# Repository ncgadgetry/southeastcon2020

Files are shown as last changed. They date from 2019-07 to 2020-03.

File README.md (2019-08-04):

# Southeastcon 2020 

This github contains the rules, arena control software and hardware, and other related files for the IEEE Southeastcon 2020 hardware competition to be held in Raleigh, NC on March 14, 2020.

# Contents:

* Rules:

   Latest copy of the rules, and historical copies of earlier versions.

* ArenaControl:

   Release of the Arduino code and hardware for the arena electronics.
   Please read the comments in the main ArenaControl.h file for an offer
   of fame (and 'fortune') for helping locate and resolve issues in the code.

* 3D_Files:

   Contains the OpenSCAD source code for generating the 3D images of the 
   arena in the rules, as well as the generated photos.

You can find out more about SoutheastCon 2020, including the other
competitions (software, hackathan, website, T-shirt design, ethics)
at the official SoutheastCon page here:

   https://attend.ieee.org/southeastcon-2020/

Have fun, and I hope to see you in Raleigh in March, 2020!

---------

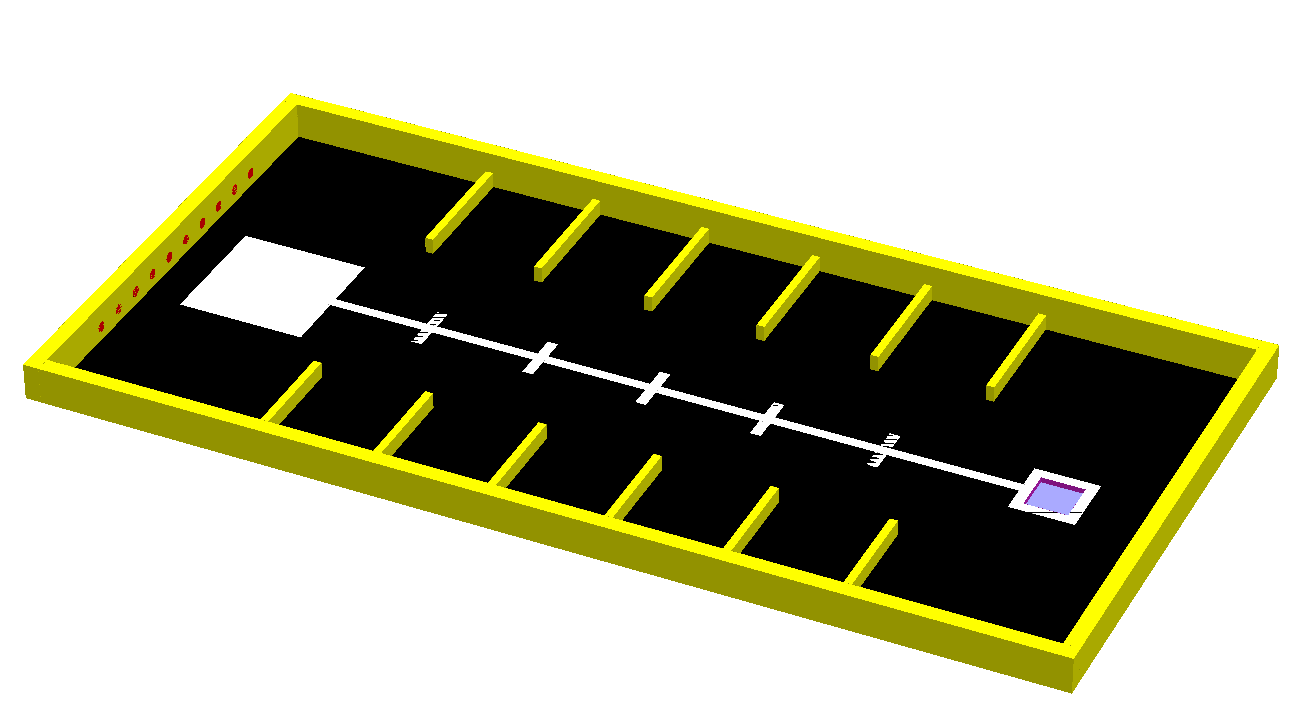
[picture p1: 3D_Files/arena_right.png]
Arena view


---------

Fun table #1 - how high a stack of Lego bricks can you build if you have N
of each color? For example, if you have one of each color, you can go 3.14,
but then run out when you hit 3.141. This table gives you that detail
for up to 25x of each color:

| #bricks | max seq | height |
|:---:|:-----:|:-----:|
| 1 | 3 | 2.3" |
| 2 | 10 | 7.6" |
| 3 | 17 | 12.9" |
| 4 | 24 | 18.1" |
| 5 | 25 | 18.9" |
| 6 | 27 | 20.4" |
| 7 | 43 | 32.5" |
| 8 | 46 | 34.8" |
| 9 | 58 | 43.8" |
| 10 | 62 | 46.9" |
| 11 | 79 | 59.7" |
| 12 | 80 | 60.5" |
| 13 | 100 | 75.6" |
| 14 | 107 | 80.9" |
| 15 | 113 | 85.4" |
| 16 | 124 | 93.7" |
| 17 | 134 | 101.3" |
| 18 | 147 | 111.1" |
| 19 | 150 | 113.4" |
| 20 | 152 | 114.9" |
| 21 | 161 | 121.7" |
| 22 | 171 | 129.3" |
| 23 | 186 | 140.6" |
| 24 | 197 | 148.9" |
| 25 | 204 | 154.2" |

---------

Fun table #2 - if you want to build a stack of a specific height, how many
blocks of each color do you need? Which color runs out the fastest at
any specific height, etc?

| count | BLACK | BROWN | RED | ORANGE |YELLOW | GREEN | BLUE | VIOLET | GRAY |WHITE |
|:---:|:---:|:---:|:---:|:---:|:---:|:---:|:---:|:---:|:---:|:---:|
| 1 | 0 | 0 | 0 | 1 | 0 | 0 | 0 | 0 | 0 | 0 |
| 2 | 0 | 1 | 0 | 1 | 0 | 0 | 0 | 0 | 0 | 0 |
| 3 | 0 | 1 | 0 | 1 | 1 | 0 | 0 | 0 | 0 | 0 |
| 4 | 0 | 2 | 0 | 1 | 1 | 0 | 0 | 0 | 0 | 0 |
| 5 | 0 | 2 | 0 | 1 | 1 | 1 | 0 | 0 | 0 | 0 |
| 6 | 0 | 2 | 0 | 1 | 1 | 1 | 0 | 0 | 0 | 1 |
| 7 | 0 | 2 | 1 | 1 | 1 | 1 | 0 | 0 | 0 | 1 |
| 8 | 0 | 2 | 1 | 1 | 1 | 1 | 1 | 0 | 0 | 1 |
| 9 | 0 | 2 | 1 | 1 | 1 | 2 | 1 | 0 | 0 | 1 |
| 10 | 0 | 2 | 1 | 2 | 1 | 2 | 1 | 0 | 0 | 1 |
| 11 | 0 | 2 | 1 | 2 | 1 | 3 | 1 | 0 | 0 | 1 |
| 12 | 0 | 2 | 1 | 2 | 1 | 3 | 1 | 0 | 1 | 1 |
| 13 | 0 | 2 | 1 | 2 | 1 | 3 | 1 | 0 | 1 | 2 |
| 14 | 0 | 2 | 1 | 2 | 1 | 3 | 1 | 1 | 1 | 2 |
| 15 | 0 | 2 | 1 | 2 | 1 | 3 | 1 | 1 | 1 | 3 |
| 16 | 0 | 2 | 1 | 3 | 1 | 3 | 1 | 1 | 1 | 3 |
| 17 | 0 | 2 | 2 | 3 | 1 | 3 | 1 | 1 | 1 | 3 |
| 18 | 0 | 2 | 2 | 4 | 1 | 3 | 1 | 1 | 1 | 3 |
| 19 | 0 | 2 | 2 | 4 | 1 | 3 | 1 | 1 | 2 | 3 |
| 20 | 0 | 2 | 2 | 4 | 2 | 3 | 1 | 1 | 2 | 3 |
| 21 | 0 | 2 | 2 | 4 | 2 | 3 | 2 | 1 | 2 | 3 |
| 22 | 0 | 2 | 3 | 4 | 2 | 3 | 2 | 1 | 2 | 3 |
| 23 | 0 | 2 | 3 | 4 | 2 | 3 | 3 | 1 | 2 | 3 |
| 24 | 0 | 2 | 3 | 4 | 3 | 3 | 3 | 1 | 2 | 3 |
| 25 | 0 | 2 | 3 | 5 | 3 | 3 | 3 | 1 | 2 | 3 |
| 26 | 0 | 2 | 3 | 6 | 3 | 3 | 3 | 1 | 2 | 3 |
| 27 | 0 | 2 | 3 | 6 | 3 | 3 | 3 | 1 | 3 | 3 |
| 28 | 0 | 2 | 3 | 7 | 3 | 3 | 3 | 1 | 3 | 3 |
| 29 | 0 | 2 | 4 | 7 | 3 | 3 | 3 | 1 | 3 | 3 |
| 30 | 0 | 2 | 4 | 7 | 3 | 3 | 3 | 2 | 3 | 3 |
| 31 | 0 | 2 | 4 | 7 | 3 | 3 | 3 | 2 | 3 | 4 |
| 32 | 0 | 2 | 4 | 7 | 3 | 4 | 3 | 2 | 3 | 4 |
| 33 | 1 | 2 | 4 | 7 | 3 | 4 | 3 | 2 | 3 | 4 |
| 34 | 1 | 2 | 5 | 7 | 3 | 4 | 3 | 2 | 3 | 4 |
| 35 | 1 | 2 | 5 | 7 | 3 | 4 | 3 | 2 | 4 | 4 |
| 36 | 1 | 2 | 5 | 7 | 3 | 4 | 3 | 2 | 5 | 4 |
| 37 | 1 | 2 | 5 | 7 | 4 | 4 | 3 | 2 | 5 | 4 |
| 38 | 1 | 3 | 5 | 7 | 4 | 4 | 3 | 2 | 5 | 4 |
| 39 | 1 | 3 | 5 | 7 | 4 | 4 | 3 | 2 | 5 | 5 |
| 40 | 1 | 3 | 5 | 7 | 4 | 4 | 3 | 3 | 5 | 5 |
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

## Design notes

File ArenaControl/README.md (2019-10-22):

# Southeastcon 2020 Arena control code

This is the Arduino control code for the arena. It is designed to run
on an Arduino Mega (1280 or 2560).

The 10 push buttons and 10 LEDs are wired to pins 26 - 35 as shown below:

     ------  -- -- -- -- -- -- -- -- -- --
     ID #     0  1  2  3  4  5  6  7  8  9
     ------  -- -- -- -- -- -- -- -- -- --
     LED     26 28 30 32 34 36 38 40 42 44 
     BUTTON  27 29 31 33 35 37 39 41 43 45
     ------  -- -- -- -- -- -- -- -- -- --

The LEDs are wired such that the cathodes of all the LEDs are tied to
ground and the anodes tied to the pins listed above.

The button switches are wired such that one half of each button is
connected to ground and the other side to the pin listed above.

Note it is possible to run a single ground wire across all 10x buttons
tying the 20x points of the LEDs and switches together. To make it 
easier, I used a 22 gauge uninsulated wire and just stiched it through
all the pins (orienting the buttons so that the LED cathode and one
side of the switch is nearest the floor.

That leaves one ground connection for all 10x switches, followed by
20x additional wires as shown in the table above.

I used the following Arduino screw shield for making the connections 
to the Arduino and the buttons and LEDs:

https://www.amazon.com/gp/product/B01N2N7LZA/ref=ppx_yo_dt_b_asin_title_o09_s00?ie=UTF8&psc=1

This should be clear enough without a schematic, but if there is any
question, please let me know.

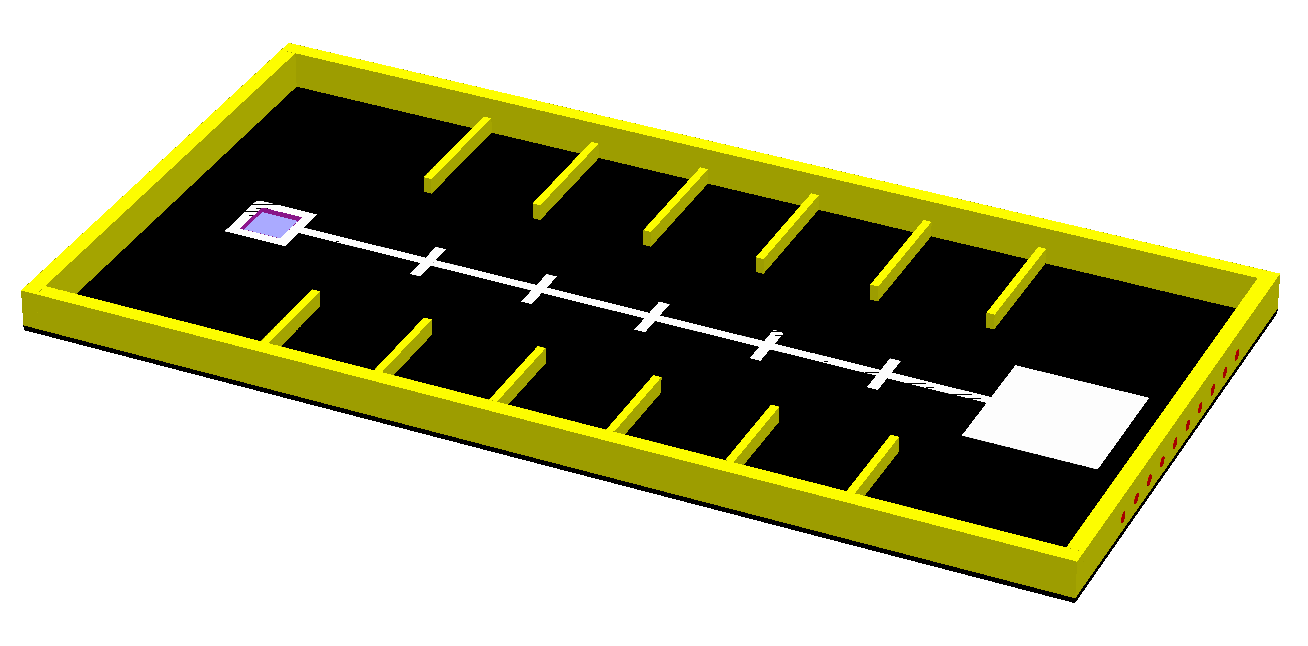
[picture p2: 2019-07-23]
3D_Files/arena_left.png

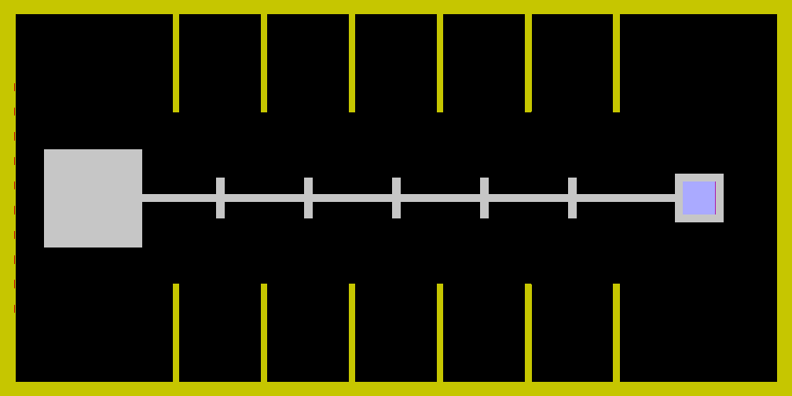
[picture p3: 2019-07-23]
3D_Files/arena_top.png

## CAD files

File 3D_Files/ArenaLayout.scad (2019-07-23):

// ****************************************************************
// 2020 IEEE SoutheastCon Hardware Competition
// Pi-Day competition
// ****************************************************************

// Conversion factors
inch  = 25.4; // mm to inch conversion
fudge = 0.1;  // mm for z-fighting

// Standard lumber dimensions
by1 = 0.75*inch;
by2 = 1.5*inch;
by4 = 3.5*inch;
halfInchPly = 15/32*inch; // nominal 0.5"

// Arena drawFloor dimensions
arenaX = 8*12*inch;
arenaY = 4*12*inch;
arenaZ = halfInchPly;

// Arena colors
floor_color  = "black";
wall_color   = "yellow";
stripe_color = "white";
button_color = "red";

stripeWidth = 1*inch;
markerWidth = 5*inch;

// Starting square and tower hole dimensions
startSquare = 12*inch;
startCenterOffset = by2 + 9.5*inch;
holeSize    = 4*inch;
holeCenterOffset = arenaX - by2 - 9.5*inch;

binWidth = 10*inch;
binDepth = 12*inch;
bin1Xoffset = arenaX/2 - (2.5*binWidth) - 3*by1;

buttonSpacing = 3*inch;



// ****************************************************************
// Draw the center line and the bin navigation marker lines
// ****************************************************************

module drawFloorLines()
{
    color(stripe_color) {

        // Stripe down the middle of the bins
        translate([startCenterOffset, (arenaY-stripeWidth)/2, arenaZ])
           cube([holeCenterOffset - startCenterOffset, stripeWidth, fudge]);

        // Draw the alignment markers for each bin on middle line
        for(bin=[0:4]) {
           translate([bin1Xoffset + 
                     (bin+1)*by1 + 
                     (bin+0.5)*binWidth -
                     stripeWidth/2,
                     (arenaY-markerWidth)/2, arenaZ])
              cube([stripeWidth, markerWidth, fudge]);
        }

        // Draw the square around the tower hole
        translate([holeCenterOffset,arenaY/2,arenaZ])
           cube([holeSize+2*stripeWidth,
                 holeSize+2*stripeWidth,
                 fudge], center=true);

    }
}


// ****************************************************************
// Draw the starting square
// ****************************************************************

module drawStartingSquare()
{
    color(stripe_color) 
        translate([startCenterOffset, arenaY/2, arenaZ])
        cube([startSquare, startSquare, fudge], center=true);
}


// ****************************************************************
// Draw the floor of the arena (4' x 8' black plywood), with a hole
//    cut out of it on end for the stacking tower (teams are 
//    responsible for providing their own stacking surface to 
//    place within the hold to isolate it from the vibrations of
//    the arena floor)
// ****************************************************************

module drawFloor()
{
    difference() {
       union() {
           // First draw the plywood floor
           color(floor_color) 
               cube([arenaX, arenaY, arenaZ]);
           drawFloorLines();
           drawStartingSquare();
       }

       // Then cut a hole out of the middle of it
       translate([holeCenterOffset,arenaY/2,-fudge])
          cube([holeSize,holeSize,(arenaZ+fudge)*3], center=true);
    }
}


// ****************************************************************
// Draw the 2x4 walls
// ****************************************************************

module drawWalls()
{
    color(wall_color) union() {

        // left wall
        translate([by2, 0, arenaZ]) 
           cube([arenaX-by2, by2, by4]);

        // right wall
        translate([0, arenaY-by2, arenaZ]) 
           cube([arenaX-by2, by2, by4]);

        // front wall (nearest tower hole)
        translate([arenaX-by2, by2, arenaZ]) 
           cube([by2, arenaY-by2, by4]);

        // back wall (pushbutton wall)
        translate([0, 0, arenaZ]) 
           cube([by2, arenaY-by2, by4]);
    }
}


// ****************************************************************
// Each bin wall is a 1x2, mounted with the 3/4" side on the plywood
//    and the 1.5" standing vertical - one wall between each bin and
//    since we have 5 bins on each wall, that is 6 walls on each side
// ****************************************************************

module drawBinWalls()
{
    color(wall_color) {

        for(wall=[0:5]) {
           translate([bin1Xoffset + wall*(binWidth+by1), 0, arenaZ]) {
              translate([0, by2, 0])
                 cube([by1,binDepth,by2]);
              translate([0, arenaY - by2 - binDepth, 0])
                 cube([by1,binDepth,by2]);
           }
        }
    }
}



// ****************************************************************
// Draw the pushbuttons
// ****************************************************************

module drawPushbuttons()
{
    for(button=[0:9]) {
        translate([by2, 
                   (button - 4.5) * buttonSpacing + arenaY/2,
                   by4/2])
        rotate([0, -90, 0])
            color(button_color)
               cylinder(r=0.5*inch, h=by2+fudge);
    }
}


// ****************************************************************
// Draw the entire arena by invoking each of the arena drawing modules
// ****************************************************************

module drawArena()
{
    drawFloor();
    drawWalls(); 
    drawBinWalls();
    drawPushbuttons();
}


// ****************************************************************
// Draw the arena, centering it over [0,0,0]
// ****************************************************************

translate([-arenaX/2,-arenaY/2, 0]) 
   drawArena();    

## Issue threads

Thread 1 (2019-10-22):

Arduino Code Not Counting First Incorrectly Pressed Button

ammrat13, 2019-10-22:
I was put in charge of simulating the button pushing code for Georgia Tech's IEEE Robotics Team, and while doing so, I think I uncovered a bug. I essentially did my best to copy your `ArduinoControl.ino` file as closely as possible. I noticed that, when testing to make sure incorrect presses are scored correctly (which I did by pressing `0` a thousand times), I recieved a score one lower than expected. I recieved a score of `999` instead of `1000`.

I traced through both my and your code and found the relevant source lines in my code to be `simulator/Buttons.py` lines `271` to `285`, which correspond to `ArduinoControl.ino` lines `257` to `298`. It seems that on the first incorrect press (`inSequence == true` and `newPress == true` and `buttonState[digit].buttonState == false`), your code correctly sets `numSequenced` to `piDigitPosn` but forgets to increment `extraNotPressed`.

The code is available on our repository: [GT-IEEE-Robotics/Simulator2020](https://github.com/GT-IEEE-Robotics/Simulator2020) commit `7a4a020` if you'd like to check this.

ncgadgetry, 2019-10-22:
Thank you for a valid bug report and code analysis. I will update the code to reflect your bug report in a few days and give you credit for the bug.

Thanx!

ncgadgetry, 2019-10-22:
Issue resolved in latest push - thanx!

I also added your name to the list of contributors for the code!

Closed 2019-10-22.

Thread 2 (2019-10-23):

Arduino Mega 2560 running out of dynamic memory when using ArenaControl code

mdixson2, 2019-10-23:
I have downloaded the git repo as a zip file. I opened the ArenaControl code using the Arduino 1.8.10 IDE. When uploading it to a Mega 2560 Arduino, an error occurs. It states:

"Arduino: 1.8.10 (Windows 10), Board: "Arduino/Genuino Mega or Mega 2560, ATmega2560 (Mega    2560)
Sketch uses 13930 bytes (5%) of program storage space. Maximum is 253952 bytes.
Global variables use 10284 bytes (125%) of dynamic memory, leaving -2092 bytes for local variables. Maximum is 8192 bytes.
Not enough memory;
Error compiling for board Arduino/Genuino Mega or Mega 2560."

Is there a fix for this issue?

mdixson2, 2019-10-23:
Thank you. That works

mlaga97, 2019-10-23:
You'll likely want to keep the issue open until the issue has been resolved on the master branch.

Closed 2019-10-23.

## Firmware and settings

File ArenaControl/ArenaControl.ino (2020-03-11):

/**
 * SoutheastCon 2020 Arena control - ArenaControl.cpp
 *
 * Pin assignments, as well as a challenge to the code reviwers
 *    to find bugs, and the list of those who helped, are listed
 *    in the ArenaControl.h file
 *
 */
 
#include "Arduino.h"
#include "ArenaControl.h"
#include "pi10000.h"


/**
 * buttonPressed - returns true if switch is depressed, else false 
 *   
 * The switch input is active-low, as the other side of the switch
 *    is tied to ground. This allows connecting all 10x of the 
 *    switches to all 10x of the LED returns together with one
 *    ground wire (see photos in hw-uploads channel)
 */
boolean buttonPressed(int id) {
   return !digitalRead(BUTTON_PIN(id));   
}


/**
 * setLED - turns on the LED if is_on is true, else turns it off
 */
void setLED(int id, boolean is_on) {
   digitalWrite(LED_PIN(id), (is_on ? HIGH : LOW));
}


/**
 * setAllLEDs - sets all the LEDs to either on or off
 */
void setAllLEDs(boolean is_on) {

   int led_id;
   
   for (led_id=0; led_id < NUM_BUTTONS; led_id++) {
      setLED(led_id, is_on);
   }
}


/**
 * piDigit - returns the 0..9 value of the dig at posn
 */
int piDigit(int posn) {
   return pgm_read_byte_near(pi + posn) - '0';
}


/**
 * flashAllLEDs - turns all the LEDs on, and sets a timeout of when to
 *    turn them all off. If called again before the timeout is up, it 
 *    just resets the timeout (so a fast robot continuing to press the
 *    wrong button will not see the LEDs go off, but will continue to 
 *    count as invalid digits if the delay is more than the timeout)
 */
void flashAllLEDs() {

   // Turn on all the LEDs, and set a time to turn them off again
   setAllLEDs(true);
   flashTimeout = millis() + FLASH_INTERVAL;
}


/**
 * Scan all the buttons, debouncing each, and sets newPress true if at 
 *   least one of the buttons transitioned from not pressed to pressed
 *   on this pass, and returns the count of on buttons in numPressed
 * 
 * The debounce logic is based on the example here of one button:
 *    http://www.arduino.cc/en/Tutorial/Debounce
 */
void debounceButtons(boolean *newPress, int *numPressed) {

   int  digit;
   uint32_t now_us = micros();
   
   *newPress = false;
   *numPressed = 0;
   
   // Scan each of the buttons   
   for (digit=0; digit < NUM_BUTTONS; digit++) {
      
     // Read the state of the switch into a local variable:
     int reading = buttonPressed(digit);
   
     // Check to see if you just pressed the button
     // (i.e. the input went from false to true), and you've waited long enough
     // since the last press to ignore any noise:   
     
     // If the switch changed, due to noise or pressing:
     if (reading != buttonState[digit].lastButtonState) {
        
       // Reset the debouncing timer
       buttonState[digit].lastDebounceTime = now_us;
     }
   
     // whatever the reading is at, it's been there for longer than the debounce
     // delay, so take it as the actual current state:
     if ((now_us - buttonState[digit].lastDebounceTime) >= DEBOUNCE_DELAY) {
  
       // if the button state has changed:
       if (reading != buttonState[digit].buttonState) {
         buttonState[digit].buttonState = reading;

         // If any button was just pressed, we set the new press boolean
         if (buttonState[digit].buttonState) {
            *newPress = true;
         }
       }
     }

   // If this button is on, increment our count of numPressed       
   if (buttonState[digit].buttonState) {
      (*numPressed)++;
   }
   
   // save the reading. Next time through the loop, it'll be the lastButtonState:
   buttonState[digit].lastButtonState = reading;
   }
}


/**
 * Calculate and return the current score
 */
long currentScore() {

   // 10 points for each one sequenced correctly, plus 1 point
   //   (max of 100) for those not sequenced correctly
   return (numSequenced * 10L) + min(extraNotSequenced, 100);
}


/**
 * Check to see if the optional controller is attached, and if so, use it to start and
 *     stop the match, and to display the status and score
 * The optional controller is the same one used in the 2017 SoutheastCon page and
 *     consists of a 4x20 LCD, I2C to LCD controller, and push buttons on A0 for
 *     start and A3 for stop
 */
bool controllerInstalled() {

   // Setup the button start/stop pins on the Arduino
   pinMode(BUTTON_START, INPUT_PULLUP);
   pinMode(BUTTON_STOP,  INPUT_PULLUP);

   // Check if the optional controller LCD is attached
   Wire.begin();
   Wire.beginTransmission(LCD_ADDRESS);
   bool installed = (0 == Wire.endTransmission());

   // If not, then display a status to the Arduino monitor
   if (false == installed) {
      Serial.println(F("Optional LCD controller not found"));
      Serial.println(F("Start the competition by briefly pressing any button\n"));

   // Else clear the LCD display and display start instructions
   } else {
      lcd.init();
      lcd.backlight();
      lcd.home();

      lcd.print("SoutheastCon 2020");

      lcd.setCursor(0, 1);
      lcd.print("Do you want to...");
      lcd.setCursor(0, 2);
      lcd.print("    ...play a game?");

      lcd.setCursor(0,3);
      lcd.print(" vvv Press to START");
      Serial.println(F("LCD controller FOUND - press the START button to begin"));
   }

   return installed;
}


/**
 * Returns true if either start on the optional controller or any of the 10
 *    pi buttons have been pressed
 */
bool matchStart() {

   bool started = false;

   // If started on optional controller, display stop instructions now
   if (hasController && (!digitalRead(BUTTON_START))) {
      started = true;
   }

   // If start not pressed, quickly scan to see if any of the 10 pi buttons
   //    have been pressed - we are NOT worrying about debouncing for start
   int button;
   for (button=0; button < NUM_BUTTONS; button++) {
       if (buttonPressed(button)) {
          delay(50);
          while (buttonPressed(button));
          delay(300);
          started = true;
       }
    }

    // If started and controller present, display stop directions
    if (hasController && started) {
       lcd.setCursor(0, 1);
       lcd.print("                    ");
       lcd.setCursor(0, 2);
       lcd.print("                    ");

       lcd.setCursor(0,3);
       lcd.print("Press to STOP  vvv ");      
    }
    
    // Neither start or a button pressed, so not starting yet
    return started;
}


/**
 *  Returns true if the A3 on the optional controller is pressed (no way to
 *     stop the contest if running from a laptop for testing purposes
 */
bool matchStop() {
   return (hasController and (!digitalRead(BUTTON_STOP)));
}


/**
 * Update the score on the controller LCD display
  */
void updateController(uint32_t runTime) {

      lcd.clear();
      lcd.setCursor(0, 0);
      lcd.print("TIME:  ");
      lcd.print(runTime / 1000);
      
      lcd.setCursor(13, 0);
      lcd.print("S:");
      lcd.print(numSequenced);

      lcd.setCursor(0, 1);
      lcd.print("SCORE: ");
      lcd.print(currentScore());

      lcd.setCursor(13, 1);
      lcd.print("X:");
      lcd.print(extraNotSequenced);

      lcd.setCursor(0,3);
      lcd.print("RESET for next game");
}
 
 /**
 * Do whatever set up is required to wait for the competition to start,
 *    and to display the first digit (add a little LED bling of bouncing
 *    LED lights while waiting for the contest to start
 */
void startCompetition() {

   uint32_t ledDelay = 500;      // for a 2hz rate
   uint32_t start = millis();    // start of delay for each led dance
   int led = 1;                  // where to start the dance
   int direction = -1;           // initial direction of the light dance
   
   // The judge starts the competition by pressing any one button
   // For fun, do a bouncing LED back and forth until the button press
   while (!matchStart()) {

      // Is it time to move to the next LED?
      if ((millis() - start) > ledDelay) {
 
         // If so, turn the previous one off, advance, turn next on
         start = millis();
         setLED(led, false);
         led += direction;
         setLED(led, true);
 
         // Is it time to reverse direction?
         if ((led == 0) or (led == 9)) {
            direction = -direction;
         }
      }
   }

   // Quick flash to indicate the competition has begun
   setAllLEDs(true);
   delay(FLASH_INTERVAL);
   setAllLEDs(false);

   // Pause a bit to make sure judge lets go of the start button... ;-)
   delay(100);
}


/**
 * endCompetition - turn on all LEDs, show score, halt
 */
void endCompetition(uint32_t runTime) {
      
   // Turn on all the LEDs to indicate the competition is over
   setAllLEDs(true);

   // If no sequence errors so far, num sequenced is our position!   
   if (inSequence) {
      numSequenced = piDigitPosn;
   }

   // Print out the stats on presses
   Serial.println(F("Time's up\n"));
   Serial.print(F("Num sequenced correctly:"));
   Serial.println(numSequenced);
   Serial.print(F("Extra not sequenced correctly:"));
   Serial.println(extraNotSequenced);

   // Display the final score
   Serial.print(F("\nFinal score: "));
   Serial.println(currentScore());

   if (hasController) {
      updateController(runTime);
   }

   
   // Wait here forever...
   for(;;);
}


/**
 * setup - this is executed once at the start of the sketch, so perform any
 *    necessary setup operations here
 */
void setup() {

   int i;
   
   // Enable the debug outputs and set them low
   digitalWrite(ERROR_STATE, LOW);
   pinMode(ERROR_STATE, OUTPUT);
   digitalWrite(DEBUG_LED_ON, LOW);
   pinMode(DEBUG_LED_ON, OUTPUT);

   // Start serial and print out our version
   Serial.begin(115200);
   Serial.println(HELLO);
   Serial.println(VERSION);
   delay(50);
   
   // Setup our buttons as input and our leds as output, and turn the LEDs off
   for (i=0; i < NUM_BUTTONS; i++) {
      pinMode(LED_PIN(i), OUTPUT);
      pinMode(BUTTON_PIN(i), INPUT_PULLUP);
      setLED(i, false);
      if (buttonPressed(i)) {
         Serial.print("Warning, button #");
         Serial.print(i);
         Serial.println(" is already pressed");
      }
   }

   // Check if the optional LCD/button controller is installed
   hasController = controllerInstalled();

   // Wait for the competition to start
   startCompetition();

   // Save off the timestamp of when we started the competition
   startTimestamp = millis();
}


/**
 * loop - called continuously for as long as the Arduino is on, so perform
 *   any operations here. All operations are performed as part of a state 
 *   machine so no delays in the loop processing
 */
void loop() {

   uint32_t now = millis();
   uint32_t runTime = now - startTimestamp;
   boolean newPress;
   int numPressed;

   // If the match is over, stop and report the score now and halt here
   if ((runTime >= MATCH_RUNTIME) || (matchStop())) {
      endCompetition(runTime);  // Will not return from this
   }

   // If we are 'flashing' all LEDs, see if the flash on interval is over
   if ((flashTimeout != 0) && (now >= flashTimeout)) {
      setAllLEDs(false);
   }
   
   // Debounce all the buttons...   
   debounceButtons(&newPress, &numPressed);
   
   // If all buttons are released, then light up the next button in the sequence
   if (numPressed == 0) {
      if (inSequence) {
         digitalWrite(DEBUG_LED_ON, HIGH);
         setLED(piDigit(piDigitPosn), true);
      }
   }

   // Else we handle the case of currently in a sequence   
   else if (inSequence) {

      // If more than one button is pressed, we are no longer sequencing correctly
      if (numPressed > 1) {
         digitalWrite(ERROR_STATE, HIGH);
         inSequence = false;
         numSequenced = piDigitPosn;
         flashAllLEDs();
      }

     // Else exactly one was pressed, and this is a new press
     else if (newPress) {
        
        // Get the 0..9 value of the current sequence digit
        int digit = piDigit(piDigitPosn);

        // If the wrong button was pressed, we are no longer sequencing
        if (buttonState[digit].buttonState == false) {
           digitalWrite(ERROR_STATE, HIGH);
           inSequence = false;
           extraNotSequenced++;
           flashAllLEDs();

        // Else new press, correct so turn off digit, increment count of correct
        //   digits and light up the next digit
        } else {
           digitalWrite(DEBUG_LED_ON, LOW);
           setLED(digit, false);
           piDigitPosn++;
           numSequenced = piDigitPosn;
        }
     }
   }
   
   // And finally we handle the case of not in a sequence
   else {

      // If this is a new press, count it and flash all the digits
      if (newPress) {
         extraNotSequenced++;
         flashAllLEDs();
      }
   }
}

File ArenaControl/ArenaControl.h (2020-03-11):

/*
 * ArenaControl.h
 *
 * I encourage everyone to read through the code and help me identify any
 *    issues. This will make the arena electronics better for both me,
 *    your team, and all the other teams.
 *
 * Any person (or team) who identifies any issues will have their name (or
 *    names) listed in the collaboration section below.
 *
 * Note that only the first person to find each issue is listed.
 *
 * Trivial question - the first person (or team) who can answer this will also
 *    get their name/names listed in the honors section below.
 *    "What digit sequence occurs at position 18,900,827 and why is it important?"
 *    (the correct answer was submitted by Ben Wiegand [BigBenMOG] of the Bob
 *    Jones University team. The answer is that the sequence 0-3-1-4-2-0-2-0 is
 *    found starting at that position, which corresponds to the date of the
 *    Pi Day challenge during SoutheastCon 2020 (03/14/2020).
 *
 * COLLABORATORS / HONORS (for helping identify new issues in the software):
 *    YOUR NAME COULD BE HERE FOR EVERYONE TO SEE!
 *
 * Luc Lagarde USM - found a typo in my header comments (2029 instead of 2020)
 * Ammar Ratnani - issue with first incorrect digit not counted (also reported 
 *       by dskaggs (Dylan) of WKU`
 * Luc Lagarde USM - suggested adding PROGMEM to pi (needed once #digits 
 *       was bumped to 10k) - issue reported by mdixon2
 * dskaggs (Dylan of WKU - discovered I dropped PROGMEM on my lastest update
 * John Barnes UK - suggested using a larger value than int for the score, 
 *       and found a bug where I used a global name instead of the local param
 * Paul MacDougal - code review/analysis/test jig, resulting in several bug
 *                  fixes, and suggested dropping DEBOUNCE_DELAY to 24ms
 * 
 * VERSIONS:
 *    1.0 - initial release
 *    1.+ - bug fixes, bump digits to 10k, more bug fixes
 *    2.0 - add PROGMEM back, add VERSION # to track what is loaded on the board
 *    2.1 - change score to long, fix piDgit param
 *    2.2 - Paul MacDougal's code suggestions - thanx!
 *    3.0 - add support for LCD controller, switch to uS timing
 *    3.1 - remove LCD update every second (threw off button timing), and add
 *          debug output to aid in resolving fast button pressor issues
 */

#define HELLO   "SoutheastCon 2020 Hardware Arena Control"
#define VERSION "Version 3.1, released March 10, 2020"

#define MATCH_RUNTIME   (180L*1000L)  // 3 minutes (in milliseconds)

// DEBOUNCE_DELAY is 1ms shorter than 25ms to include the processing
//     time for the debounce (less than 1ms, but this makes sure that
//     25ms down and 25ms up works!
#define DEBOUNCE_DELAY   (24500ul) // debounce time in usec
#define FLASH_INTERVAL   25        // ms time to flash LEDs on wrong push

// PIN_OFFSET is the first pin used for this project. Every even pin
//    is an button, followed by the matching LED on the odd pin
//
//      ------ Pin LED/Button mapping -------
//      ID       0  1  2  3  4  5  6  7  8  9
//      LED     26 28 30 32 34 36 38 40 42 44 
//      BUTTON  27 29 31 33 35 37 39 41 43 45
//
// The other side of the LED and button are both tied to ground
//    This allows a single bus wire to tie 2x wires of each of
//    of the 10x buttons together to one connection - ground.
#define NUM_BUTTONS   10    // 10 digits - zero through nine
#define PIN_OFFSET    26    // Mega2560 first pin used
#define LED_PIN(n)    (PIN_OFFSET + (2*n))  // LEDs on the even pins
#define BUTTON_PIN(n) (LED_PIN(n) + 1)      // buttons on the odd pins

struct {
   int buttonState;                 // the current reading from the input pin
   int lastButtonState;             // the previous reading from the input pin
   uint32_t lastDebounceTime;       // the last time the output pin was toggled
} buttonState[NUM_BUTTONS];


uint32_t startTimestamp = 0;

uint32_t flashTimeout;              // if set, the time to turn off the LEDs

boolean inSequence = true;          // if true, we are still sequencing correctly
int numSequenced = 0;               // total number of digits scored correctly
int extraNotSequenced = 0;          // total number of other digit presses

int piDigitPosn = 0;                // current position in the Pi sequence

/**
 * Debug output to aid in resolving issues with your button presser.
 *   whenever an error is found, ERROR_STATE is set to True, and
 *   DEUG_LED_ON is set to True whenever any LED is on (indicating
 *   it is okay to press a button). This is very useful if you
 *   are utilizing a 10 button solenoid button presser and can setup
 *   a multi-channel logic analyzer for each solenoid, and the two
 *   debug lines below.
 */
#define ERROR_STATE   24
#define DEBUG_LED_ON  25

/**
 * Defines and globals for the optional LCD controller. This controller
 *    is the same design as used in my SoutheastCon 2017 competition.
 *    If the I2C device is found, the hasController global is set to 
 *    True and the LCD can be used for start, stop and final scoring.
 *    In addition, if the LCD is not present, the competition can be
 *    started by pressing any of the 10x buttons, and the final score
 *    will be sent to the monitor output
 */
#include <Wire.h>
#include "Sainsmart_I2CLCD.h"

#define LCD_ADDRESS   0x27     // I2C address of the LCD device
#define NUM_COLUMNS   20       // The LCD is a ...
#define NUM_ROWS      4        //      ... 4x20 character device
#define BUTTON_START  A0       // Start button is on A0
#define BUTTON_STOP   A3       // Stop button is on A3

Sainsmart_I2CLCD lcd(LCD_ADDRESS, NUM_COLUMNS, NUM_ROWS);

boolean hasController = false; // Set True only if the LCD is present

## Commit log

2019-07-23 add 3D scad and viewpoint files
    [ArenaLayout.scad]
2019-08-04 fix first bug - typo in header comments, and added tables to master README
    [ArenaControl.h, ArenaControl.ino]
2019-08-04 updated DUPLO size in table from 18.2mm to 19.2mm
2019-08-04 add bouncing LED sequence to buttons before contest begins
2019-08-05 slowed down pre-competition bling to avoid photosensitive light issues, and debounced the start button
    [ArenaControl.ino]
2019-10-23 add credit to mdixon2 for reporting issue with large pi string
    [ArenaControl.h]
2019-10-24 correct sample scores
2020-02-04 code fixes from Paul review/analysis
    [ArenaControl.ino]
2020-02-04 update version number and comments for Paul's fixed - previous push
    [ArenaControl.h, ArenaControl.ino]
2020-03-02 add optional controller, switch to uS timing
2020-03-02 simple switch debounce for button start
2020-03-02 debug for stuck on buttons
    [ArenaControl.ino]
